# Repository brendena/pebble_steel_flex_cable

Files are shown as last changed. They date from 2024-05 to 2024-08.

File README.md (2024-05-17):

# pebble steel flex cable
This is a atempt to figure out whats on the pebble steel flex cable.  But I'm not a electrical engineer.  So some things might be a little off.

front
back
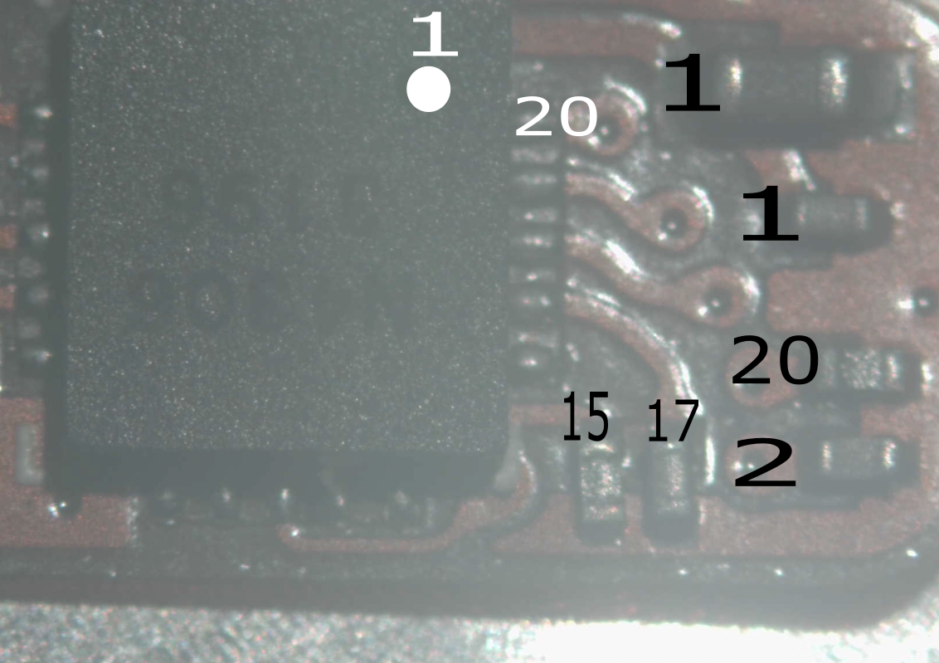
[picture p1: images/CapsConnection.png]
cap_connection


## Parts
I don't know for sure what the exact parts are.  But these seem tobe matching up very nicely.  The Ic on the top responds the exact same way as the IS31FL3199.  

* [IS31FL3199](https://www.digikey.com/en/products/detail/lumissil-microsystems/IS31FL3199-QFLS2-TR/4286437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) - LED driver
* [molex 5055511620](https://www.digikey.com/en/products/detail/molex/5055511620/10127964) 16 pin board connector.  Should be the same as in the pebble original.

## other post
* [original pebble watch](https://www.reddit.com/r/pebble/comments/10hv3ih/pebble_classic_flex_schematic/)

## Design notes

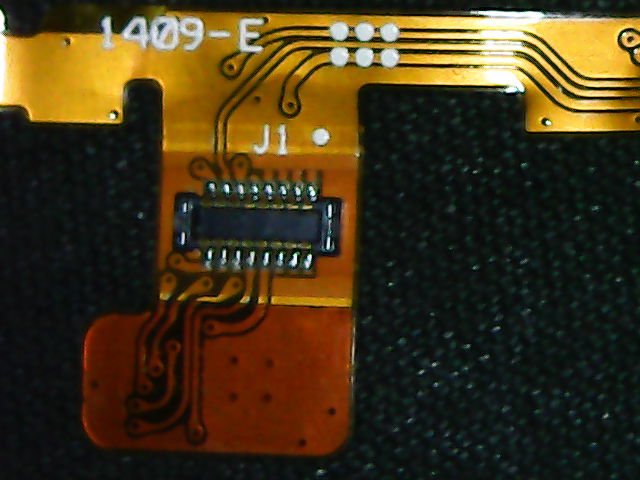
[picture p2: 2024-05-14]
images/back1.png

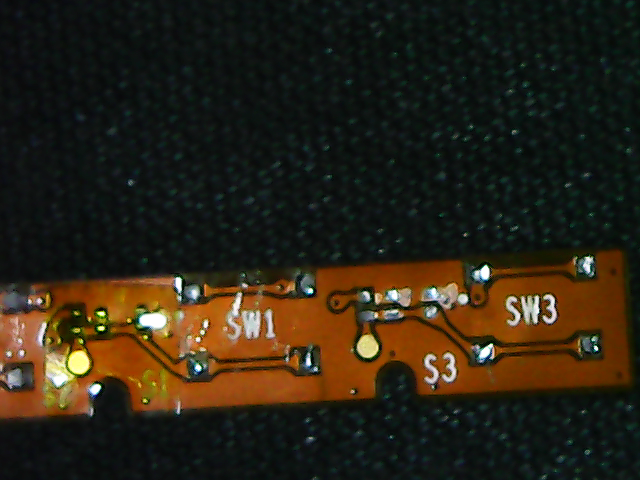
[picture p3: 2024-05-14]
images/front3Removed.png

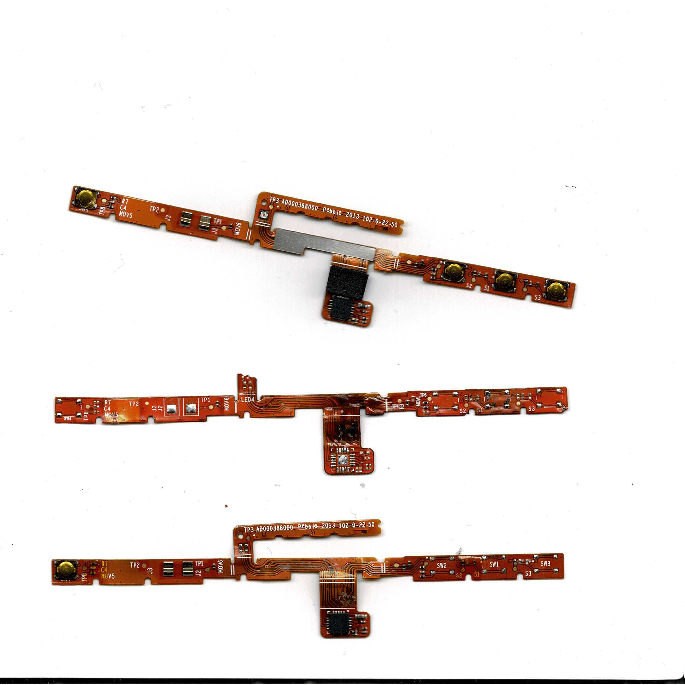
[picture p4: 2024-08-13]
images/FlatBedScanFront.jpg

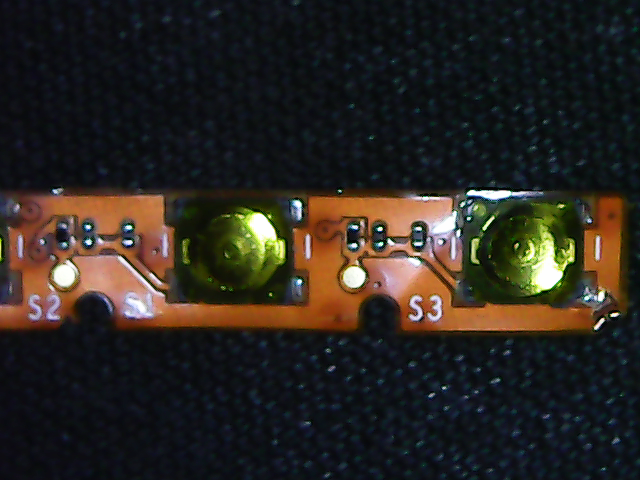
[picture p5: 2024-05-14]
images/front3.png

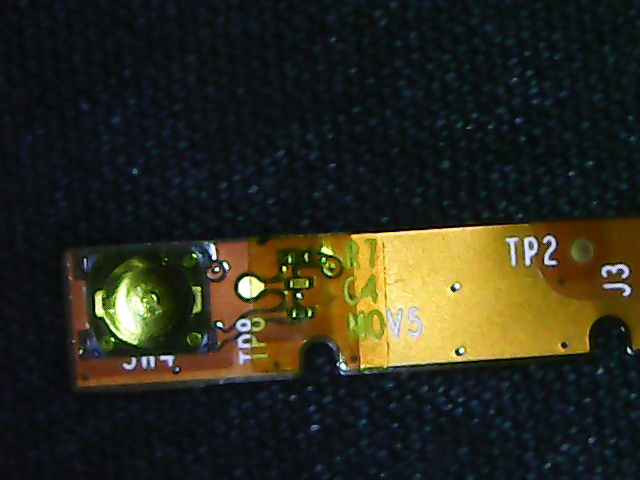
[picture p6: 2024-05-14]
images/front4.png

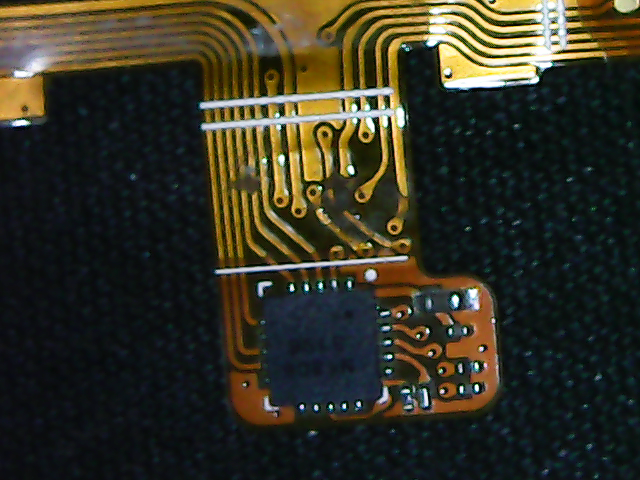
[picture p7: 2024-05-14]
images/front1.png

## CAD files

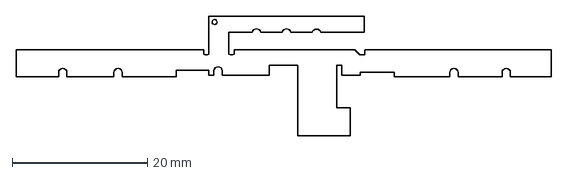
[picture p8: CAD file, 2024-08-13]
cad/flex_cable_outline-Sketch.dxf
79.2 x 17.8 mm

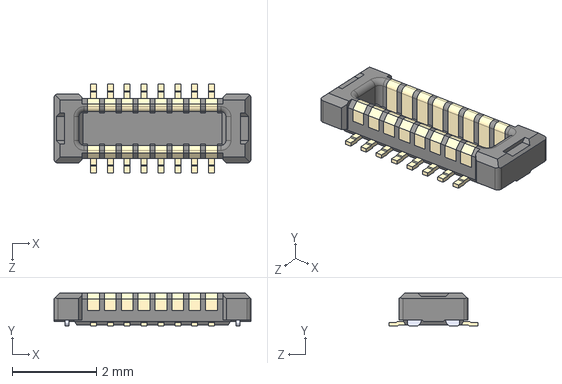
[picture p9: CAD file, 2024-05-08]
parts/molex_505551-1620/505551-1620.step
4.67 x 0.78 x 2.10 mm

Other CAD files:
cad/flex_cable_outline.FCStd

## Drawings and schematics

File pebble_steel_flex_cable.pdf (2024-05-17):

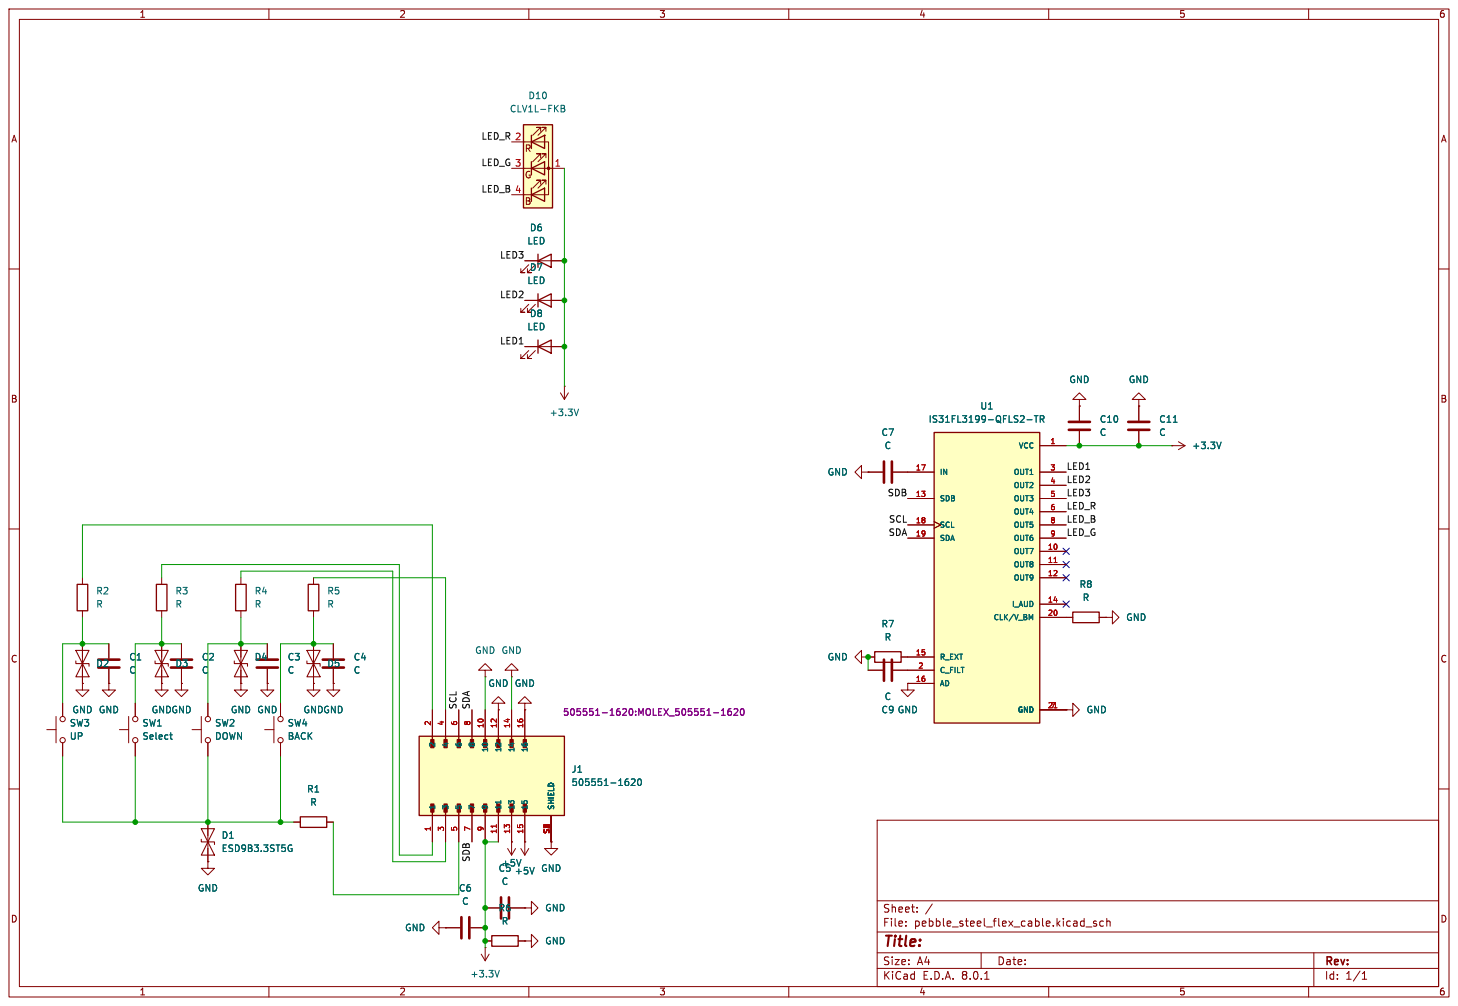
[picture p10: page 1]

Id: 1/1 Title: File: pebble_steel_flex_cable.kicad_sch Sheet: /

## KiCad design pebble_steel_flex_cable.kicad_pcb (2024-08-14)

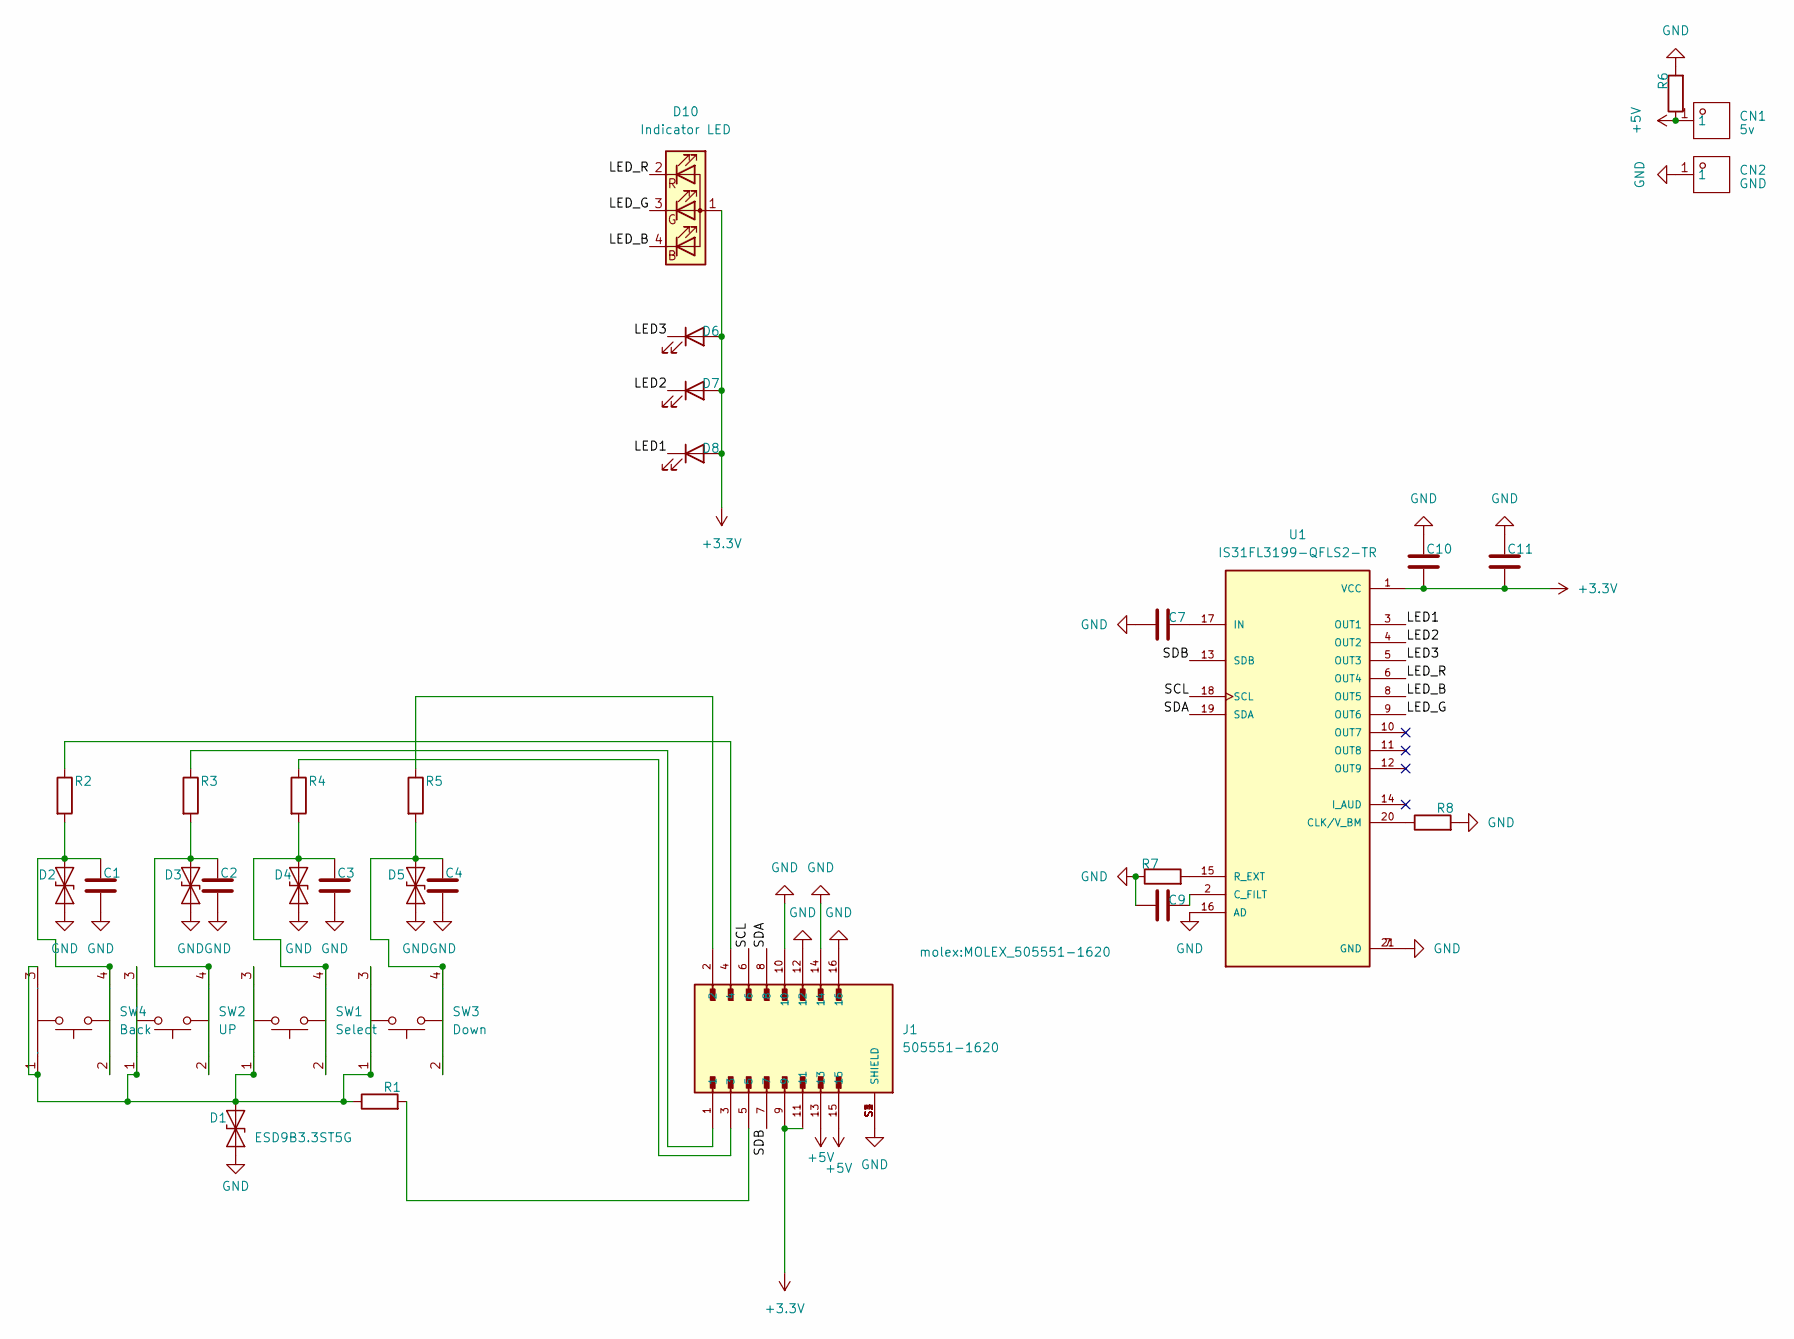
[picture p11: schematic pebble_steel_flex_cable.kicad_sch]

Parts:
C1, C2, C3, C4, C7, C9, C10, C11: C; C_0201_0603Metric
CN1: 5v; SMD_L2.7-W1.5; Manufacturer Part S7121-42R
CN2: GND; SMD_L2.7-W1.5; Manufacturer Part S7121-42R
D1, D2, D3, D4, D5: ESD9B3.3ST5G; D_SOD-923
D6, D7, D8: LED; LTW-020ZDCG
D10: Indicator LED; led_SML-LX0404SIUPGUSB
J1: 505551-1620; MOLEX_505551-1620; PARTREV B
R1, R2, R3, R4, R5, R6, R7, R8: R; R_0201_0603Metric
SW1: Select; SW-SMD_SKSHAAE010; Manufacturer Part SKSHAAE010
SW2: UP; SW-SMD_SKSHAAE010; Manufacturer Part SKSHAAE010
SW3: Down; SW-SMD_SKSHAAE010; Manufacturer Part SKSHAAE010
SW4: Back; SW-SMD_SKSHAAE010; Manufacturer Part SKSHAAE010
U1: IS31FL3199-QFLS2-TR; QFN40P300X300X80-21N; PARTREV B

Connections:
+3.3V: C10.1, C11.1, D6.2 (A), D7.2 (A), D8.2 (A), D10.1 (A), J1.9, J1.11, U1.1 (VCC)
+5V: CN1.1, J1.13, J1.15, R6.1
/LED1: D8.1 (K), U1.3 (OUT1)
/LED2: D7.1 (K), U1.4 (OUT2)
/LED3: D6.1 (K), U1.5 (OUT3)
/LED_B: D10.4 (BK), U1.8 (OUT5)
/LED_G: D10.3 (GK), U1.9 (OUT6)
/LED_R: D10.2 (RK), U1.6 (OUT4)
/SCL: J1.6, U1.18 (SCL)
/SDA: J1.8, U1.19 (SDA)
/SDB: J1.7, U1.13 (SDB)
GND: C1.2, C2.2, C3.2, C4.2, C7.1, C9.2, C10.2, C11.2, CN2.1, D1.1 (A1), D2.1 (A1), D3.1 (A1), D4.1 (A1), D5.1 (A1), J1.10, J1.12, J1.14, J1.16, J1.S1 (SHIELD), J1.S2 (SHIELD), J1.S3 (SHIELD), J1.S4 (SHIELD), R6.2, R7.1, R8.2, U1.7 (GND), U1.16 (AD), U1.21 (GND)
unnamed: D1.2 (A2), R1.1, SW1.1, SW1.3, SW2.1, SW2.3, SW3.1, SW3.3, SW4.1, SW4.3
unnamed: C1.1, D2.2 (A2), R2.2, SW4.2, SW4.4
unnamed: C2.1, D3.2 (A2), R3.2, SW2.2, SW2.4
unnamed: C3.1, D4.2 (A2), R4.2, SW1.2, SW1.4
unnamed: C4.1, D5.2 (A2), R5.2, SW3.2, SW3.4
unnamed: J1.1, R3.1
unnamed: J1.2, R5.1
unnamed: J1.3, R4.1
unnamed: J1.4, R2.1
unnamed: J1.5, R1.2
unnamed: R8.1, U1.20 (CLK/V_BM)
unnamed: C9.1, U1.2 (C_FILT)
unnamed: C7.2, U1.17 (IN)
unnamed: R7.2, U1.15 (R_EXT)

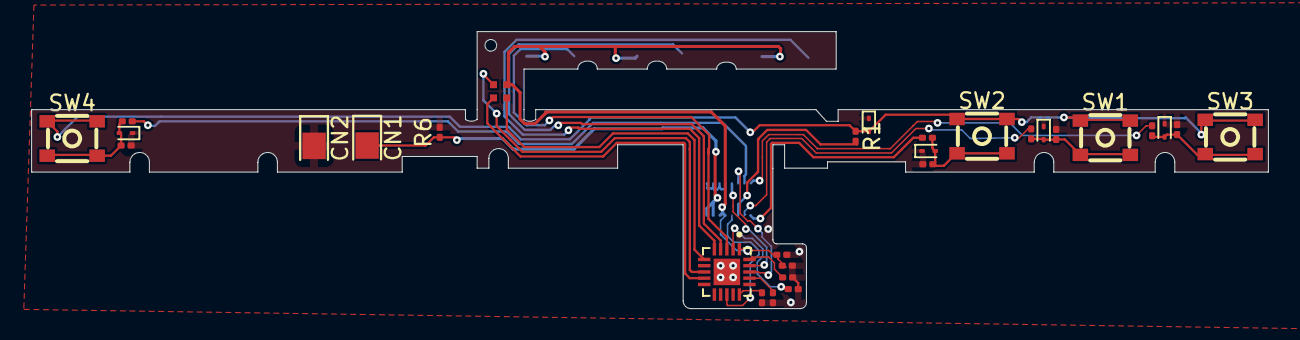
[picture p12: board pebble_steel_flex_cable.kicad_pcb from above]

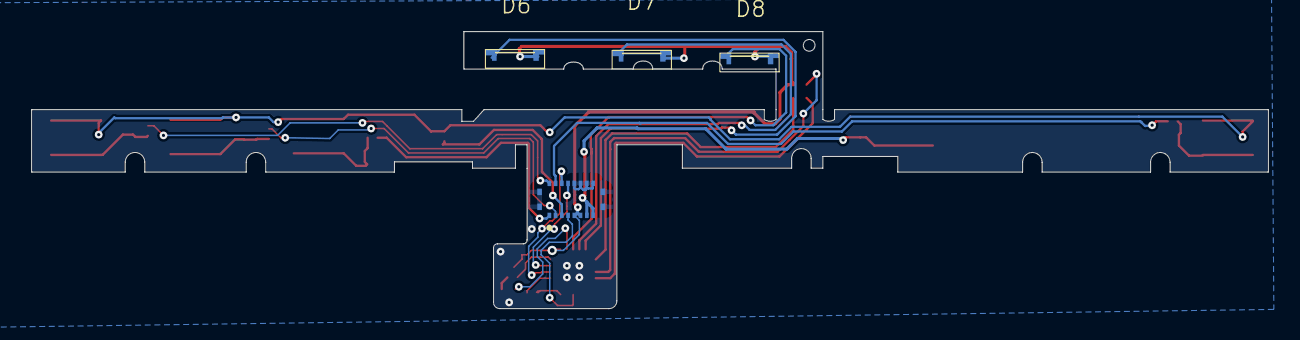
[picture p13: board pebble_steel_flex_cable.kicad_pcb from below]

Board: 2 copper layers, 79.2 x 17.8 mm, 33 parts (4 on the bottom side), 26 nets.

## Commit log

2024-05-08 start of figuring out the cable
    [505551-1620.step, pebble_steel_flex_cable.kicad_pcb, pebble_steel_flex_cable.kicad_sch]
2024-05-09 most of its mapped out
    [pebble_steel_flex_cable.kicad_sch]
2024-05-14 added some images of the cable
2024-05-17 fixed the layout and added the doc for the part
    [pebble_steel_flex_cable.kicad_sch]
2024-07-07 started layout
    [505551-1620.step, pebble_steel_flex_cable.kicad_pcb, pebble_steel_flex_cable.kicad_sch]
2024-07-07 added the buttons and the battery connections
    [pebble_steel_flex_cable.kicad_pcb, pebble_steel_flex_cable.kicad_sch]
2024-07-07 added the LED part
    [pebble_steel_flex_cable.kicad_pcb, pebble_steel_flex_cable.kicad_sch]
2024-07-16 added flat bed scans
2024-08-11 added the start of the flex cable layout
    [flex_cable_outline.FCStd]
2024-08-11 added changes
    [flex_cable_outline.FCStd]
2024-08-11 got the outline almost there
    [flex_cable_outline-Sketch.dxf, flex_cable_outline.FCStd, pebble_steel_flex_cable.kicad_pcb]
2024-08-13 got the flex layed out
    [flex_cable_outline-Sketch.dxf, pebble_steel_flex_cable.kicad_pcb, pebble_steel_flex_cable.kicad_sch]
2024-08-14 send for fit test
    [pebble_steel_flex_cable.kicad_pcb]
